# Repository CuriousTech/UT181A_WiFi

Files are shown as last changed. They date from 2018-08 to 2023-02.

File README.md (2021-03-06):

# UT181A_WiFi
Uni-T UT181A WiFi Interface  

Optically isolated interface for the UT181A using the ESP8266 for WiFi in either STA or AP mode. USB Rechargeable 1 cell LiPo and optional OLED display, which should be disabled for speed.  

The code is complete. There should be more export formats though. There's a basic web interface and binary WebSocket for a Windows software interface.  
[WindowsApp](https://www.curioustech.net/ut181a.html)  

  

Web page.  Click the white time on top to update the internal clock. The rest should be the same as what's on the DMM. 
Web  

File manager.  Click Saves or Records for listings. Click on files to download, and X to delete.  
Web

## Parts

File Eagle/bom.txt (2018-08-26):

PCB          OSHPark $7.80 for 3
ESP-07       eBay
USB Micro-B  ZX62D-B-5PA8(30) or common eBay
3V3R         MCP1755T-3302E/OT or MCP1802T-3302I/OT
CC           MCP73831T-2DCI/OT
MICROSWITCH  SSSS810701
BAT (conn)   micro jst 1.25 2 pin
P1           SFH 310
D1           IR LED (T-1)
Q1           SOT23 NPN general purpose
CHG          0805 LED (red)
PROG         4mm button (eBay)

R1           0603 10K=100mA, 2K2=454mA (charge rate)
R2-R4        0805 10K
R5           0805 47
R6           0603 470

C1,C2        0603 0.1uF 10V
C3,C4        0603 4.7uF 10V

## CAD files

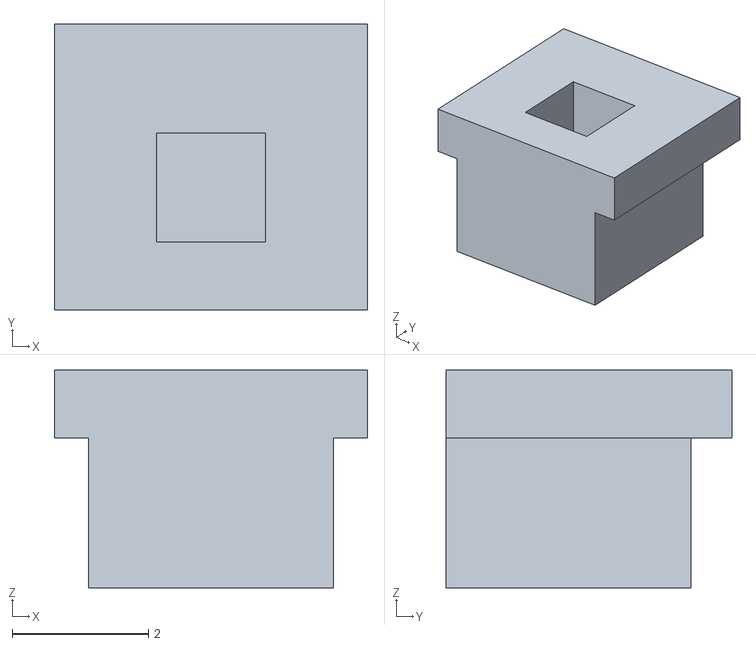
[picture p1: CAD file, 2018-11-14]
3D/switchcover.stl
4.60 x 4.20 x 3.20

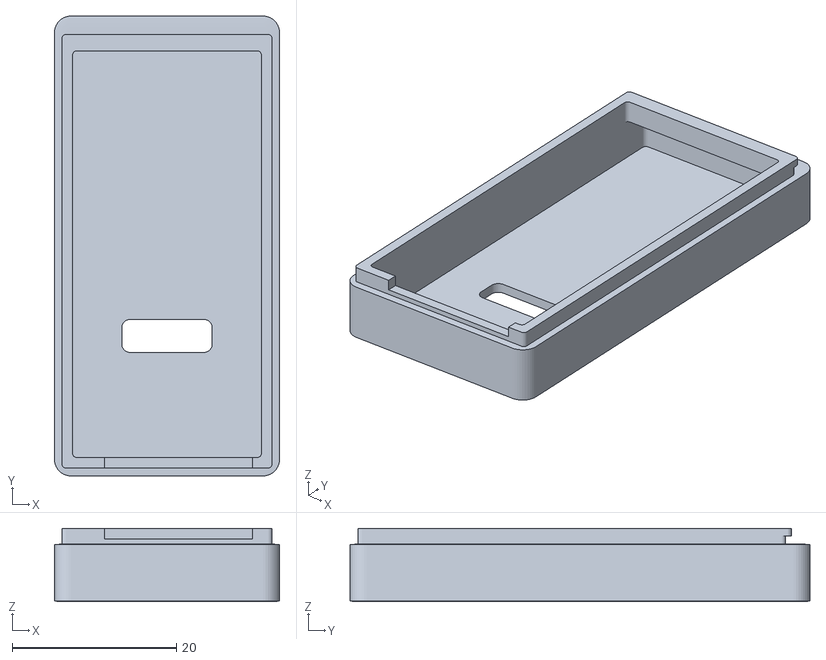
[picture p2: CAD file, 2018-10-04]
3D/UT181ACap.stl
27.4 x 56.0 x 8.90

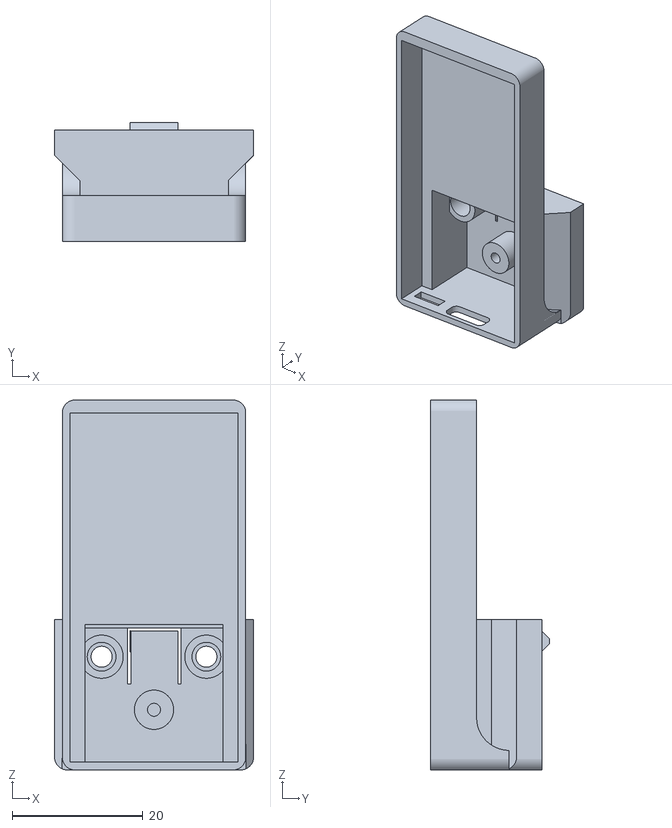
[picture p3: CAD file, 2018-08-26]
3D/UT181ACase.stl
30.4 x 18.1 x 56.5

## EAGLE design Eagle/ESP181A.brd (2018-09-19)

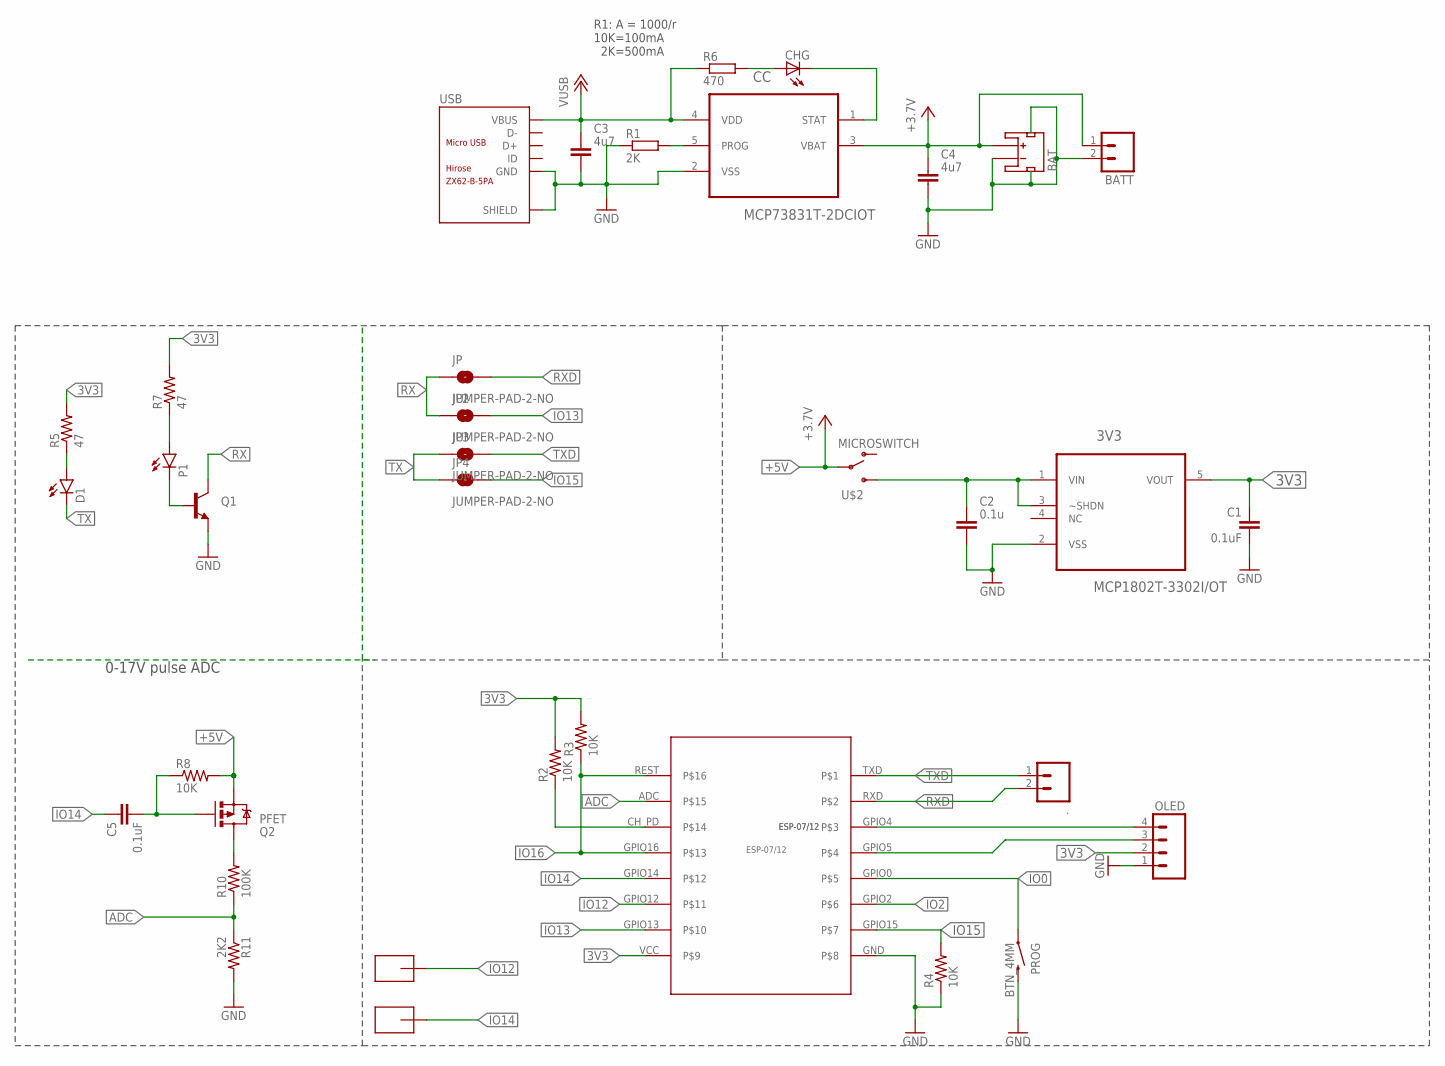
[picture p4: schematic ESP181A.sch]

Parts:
3V3: MCP1802T-3302I/OT; SOT95P270X145-5N
.: M02PTH; 1X02
BAT: JST1.25MM; JST_1.25MM
BATT: M02PTH; 1X02
C1, C5: 0.1uF; 0805-CAP
C2: 0.1u; C603
C3, C4: 4u7; C603
CC: MCP73831T-2DCIOT; SOT95P280X145-5N
CHG: LEDCHIP-LED0805; CHIP-LED0805
D1: LED3MM
JP, JP2, JP3, JP4: JUMPER-PAD-2-NO; PAD-JUMPER-2-NO_NO_SILK
OLED: M04PTH; 1X04
P1: LED3MM
PROG: BTN_4MM
Q1: TRANSISTOR_NPNSOT23-3; SOT23-3
Q2: PFET; SOT23-3
R1: 2K; R603
R2, R3, R4, R8: 10K; 0805
R5, R7: 47; 0805
R6: 470; R603
R10: 100K; 0805
R11: 2K2; 0805
U$1: ESP-07/12
U$2: MICROSWITCH
U$3, U$4: SMD-PAD182X64; SMD-PAD1
USB: ZX62-B-5PA; MICRO-USB5+6P-SMD-0.65-AB

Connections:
3V3: 3V3.5 (VOUT), C1.1, OLED.2, R2.2, R3.2, R5.2, R7.2, U$1.VCC
+5V: BAT.2 (+), BATT.1, C4.1, CC.3 (VBAT), Q2.2 (S), R8.2, U$2.2
ADC: R10.1, R11.1, U$1.ADC
CH_PD: R2.1, U$1.CH_PD
GND: 3V3.2 (VSS), BAT.1 (-), BAT.NC1 (PAD1), BAT.NC2 (PAD2), BATT.2, C1.2, C2.2, C3.2, C4.2, CC.2 (VSS), OLED.1, PROG.2, Q1.2 (E), R1.1, R4.1, R11.2, U$1.GND, USB.5 (GND), USB.P1 (SHIELD), USB.P2 (SHIELD), USB.P3 (SHIELD), USB.P4 (SHIELD), USB.P5 (SHIELD), USB.P6 (SHIELD)
IO0: PROG.1, U$1.GPIO0
IO2: U$1.GPIO2
IO12: U$1.GPIO12, U$4.>PAD
IO13: JP2.2, U$1.GPIO13
IO14: C5.1, U$1.GPIO14, U$3.>PAD
IO15: JP4.2, R4.2, U$1.GPIO15
IO16: R3.1, U$1.GPIO16, U$1.REST
unnamed: D1.A, R5.1
unnamed: P1.K (C), Q1.1 (B)
unnamed: OLED.4, U$1.GPIO4
unnamed: CHG.A, R6.2
unnamed: CC.1 (STAT), CHG.C
unnamed: OLED.3, U$1.GPIO5
unnamed: CC.5 (PROG), R1.2
unnamed: 3V3.1 (VIN), 3V3.3 (~SHDN), C2.1, U$2.3 (S)
unnamed: P1.A, R7.1
unnamed: C5.2, Q2.1 (G), R8.1
unnamed: Q2.3 (D), R10.2
RX: JP.1, JP2.1, Q1.3 (C)
RXD: ..2, JP.2, U$1.RXD
TX: D1.K (C), JP3.1, JP4.1
TXD: ..1, JP3.2, U$1.TXD
VBUS: C3.1, CC.4 (VDD), R6.1, USB.1 (VBUS)

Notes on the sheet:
R1: A = 1000/r 10K=100mA 2K=500mA
0-17V pulse ADC

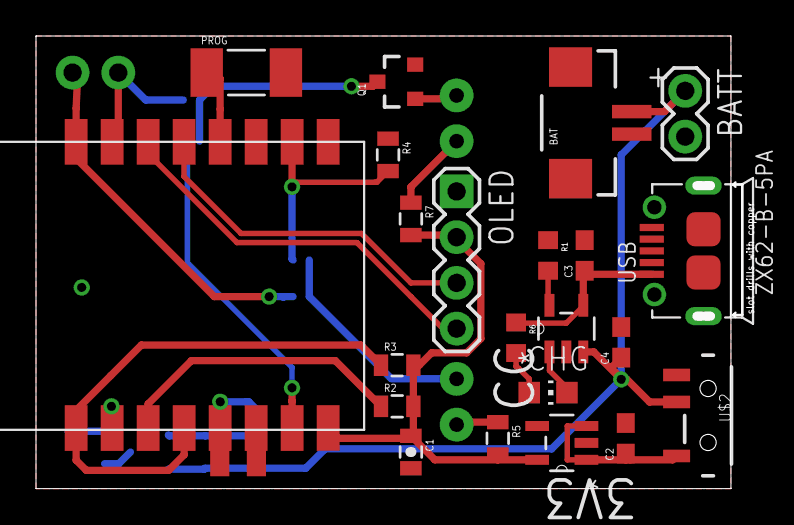
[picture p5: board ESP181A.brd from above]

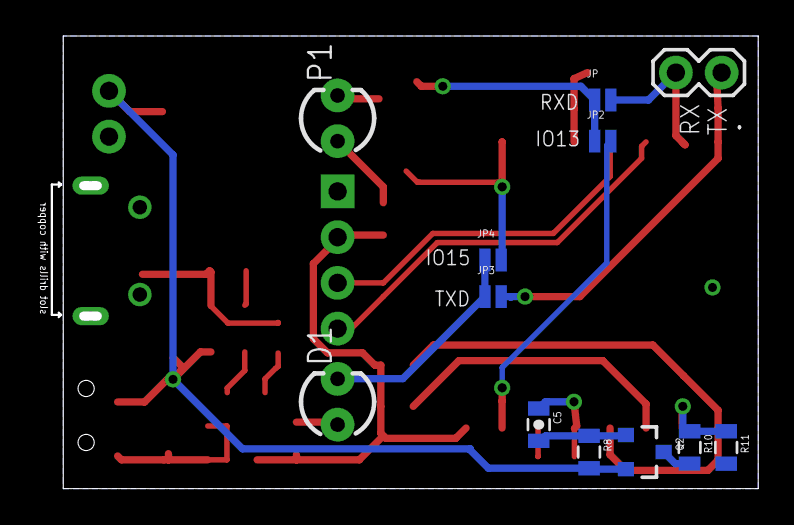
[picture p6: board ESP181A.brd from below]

Board: 2 copper layers, 39.2 x 25.1 mm, 36 parts (12 on the bottom side), 27 nets.

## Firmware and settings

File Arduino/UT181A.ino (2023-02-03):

/**The MIT License (MIT)

Copyright (c) 2018 by Greg Cunningham, CuriousTech

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
THE SOFTWARE IS PROVIDED "AS IS", WITHOUT WARRANTY OF ANY KIND, EXPRESS OR
IMPLIED, INCLUDING BUT NOT LIMITED TO THE WARRANTIES OF MERCHANTABILITY,
FITNESS FOR A PARTICULAR PURPOSE AND NONINFRINGEMENT. IN NO EVENT SHALL THE
AUTHORS OR COPYRIGHT HOLDERS BE LIABLE FOR ANY CLAIM, DAMAGES OR OTHER
LIABILITY, WHETHER IN AN ACTION OF CONTRACT, TORT OR OTHERWISE, ARISING FROM,
OUT OF OR IN CONNECTION WITH THE SOFTWARE OR THE USE OR OTHER DEALINGS IN THE
SOFTWARE.
*/

// Build with Arduino IDE 1.8.12, esp8266 SDK 2.7.1

//uncomment to enable Arduino IDE Over The Air update code
#define OTA_ENABLE

//#define USE_SPIFFS

#include <ssd1306_i2c.h> // https://github.com/CuriousTech/WiFi_Doorbell/tree/master/Libraries/ssd1306_i2c

#include <EEPROM.h>
#include "WiFiManager.h"
#include <ESPAsyncWebServer.h> // https://github.com/me-no-dev/ESPAsyncWebServer
#include <ESP8266mDNS.h>
#include <DNSServer.h>
#include <TimeLib.h> // http://www.pjrc.com/teensy/td_libs_Time.html
#include <UdpTime.h> // https://github.com/CuriousTech/
#include "eeMem.h"
#include <JsonParse.h> // https://github.com/CuriousTech/ESP8266-HVAC/tree/master/Libraries/JsonParse
#include "ut181if.h"
#include "jsonstring.h"
#ifdef OTA_ENABLE
#include <FS.h>
#include <ArduinoOTA.h>
#endif
#ifdef USE_SPIFFS
#include <FS.h>
#include <SPIFFSEditor.h>
#else
#include "pages.h"
#endif

int serverPort = 80;

#define BUTTON     0 // the prog button
#define ESP_LED    2 // low turns on ESP blue LED
#define SCL        4
#define SDA        5
#define SER2_RX   13  //
#define V_PULSE   14
#define SER2_TX   15

SSD1306 display(0x3c, 5, 4); // Initialize the oled display for address 0x3c, sda=5, sdc=4

WiFiManager wifi;  // AP page:  192.168.4.1
AsyncWebServer server( serverPort );
AsyncWebSocket ws("/ws"); // access at ws://[esp ip]/ws
AsyncWebSocket wsb("/bin"); // access at ws://[esp ip]/bin

uint32_t binClientID; // connected binary client
void jsonCallback(int16_t iName, int iValue, char *psValue);
JsonParse jsonParse(jsonCallback);
UdpTime utime;
eeMem ee;

UT181Interface ut;
uint32_t oldOpt;
uint16_t skipCnt;
uint8_t tick;
uint16_t volts;
uint32_t voltTm;

String timeFmt(uint32_t val) // convert seconds to hh:mm:ss
{
  int s = val % 60;
  int m = val / 60 % 60;
  static String st;

  st = String(val/3600);
  st += ":";
  if(m < 10) st += "0";
  st += m;
  st += ":";
  if(s < 10) st += "0";
  st += s;
  return st;
}

String dataJson() // main meter data 10Hz
{
  uint32_t nw = now();
  static uint16_t lastV;

  jsonString js("state");
  js.Var("t", nw - ( (ee.tz + utime.getDST() ) * 3600));
  js.Var("tk", tick);
  js.Var("v", ut.ValueText(0) ); // primary value
  if(ut.m_MData.ShowBar == 0 || ut.m_MData.MinMax) // invalid bar graph (use main value)
  {
    js.Var("bv", ut.ValueText(0));
  }
  else  // 10Hz bar value
  {
    js.Var("bv", (ut.m_MData.type == 6) ? ut.m_MData.u.Ext.Value3.fValue : ut.m_MData.u.Std.fBarValue);
  }

  js.Var("u", ut.UnitText() ); // unit of measurement
  if(ut.m_MData.Recording) // recording timer
  {
    js.Var("v1", timeFmt(ut.m_MData.u.RecTimer.dwElapsed) );
    js.Var("v2", timeFmt(ut.m_MData.u.RecTimer.dwRemain) );
    js.Var("v3", ut.m_MData.u.RecTimer.dwSamples );
  }
  else // normal and others
  {
    if(ut.m_MData.Comp) // comp mode
    {
      const char *p = "PASS";
      if(ut.m_MData.Switch == 4 && ut.m_MData.Select >1) // temp
      {
        if(ut.m_MData.u.CompTemp.Fail) p = "FAIL";
      }
      else if (ut.m_MData.u.Std.Fail) p = "FAIL";
      js.Var("v1", p);
    }
    else
      if(ut.DisplayCnt()>1) js.Var("v1", ut.ValueText(1) );
    if(ut.DisplayCnt() > 2) js.Var("v2", ut.ValueText(2) );
    if(ut.DisplayCnt() > 3) js.Var("v3", ut.ValueText(3) );
  }

  int nMin, nMax, nMod;
  ut.RangeMod(nMin, nMax, nMod);  // min/max/modulo for bar display
  String s = String(nMin) + ",";
  s += nMax; s += ","; s += nMod; 
  js.Var("mm", s);

  bool bAdd = (ut.m_MData.Value.L || ut.m_MData.Value.Blank || ut.m_MData.LeadErr || ut.m_MData.Hold) ? false:true; // skip blanks
  if(ut.Connected() == false) bAdd = false;
  static uint16_t skipList[] = {0,1,4,9,19,49,99,299,599}; // chart logging frequency
  if(ee.rate)
  {
    if(skipCnt++ >= skipList[ee.rate])
      skipCnt = 0;
    else bAdd = false;
  }
  uint16_t st = ut.StatusBits();
  if(bAdd) st |= 1; // add to chart
  js.Var("st", String(st, HEX) ); // bit flags in HEX

  if(ut.m_MData.MinMax) // min max trigger times
  {
    js.Var("t1", ut.m_MData.u.MM.dwTime1);
    js.Var("t2", ut.m_MData.u.MM.dwTime2);
    js.Var("t3", ut.m_MData.u.MM.dwTime3);
  }
  else if(ut.m_MData.Recording)
  {
    js.Var("t1", ut.m_MData.u.RecTimer.dwElapsed);
    js.Var("t2", ut.m_MData.u.RecTimer.dwRemain);
    js.Var("t3", ut.m_MData.u.RecTimer.dwSamples);
  }

  if(nw - voltTm >= 10 || volts != lastV) // every 10 seconds
  {
    voltTm = nw;
    lastV = volts;
    js.Var("vlt", (float)volts / 1000);
  }

  return js.Close();
}

void fixDeg(char *p) // deg kills websocket (try \xB0)
{
  if(*p == 0xB0) *p = '@'; // convert degree to ampersand
  if(p[1] == 0xB0) p[1] = '@';
}

String rangesJson() // get range and select options for dropdowns
{
  const char *rangeList[10][3][10] = {
    {{"Auto", "6", "60", "600", "1000", NULL}, {"Auto", NULL}, {"Auto", NULL}},
    {{"Auto", "600", "60", NULL}, {"Auto", NULL}, {"Auto",NULL}},
    {{"Auto", "6", "60", "600", "1000", NULL}, {"Auto",NULL}, {"Auto",NULL}},
    {{"Auto", "60", "600", NULL}, {"Auto",NULL}, {"Auto",NULL}},
    {{"Auto", "600", "6k", "60k", "600k", "6M", "60M", NULL}, {"Auto",NULL}, {"Auto",NULL} },
    {{"Auto",NULL}, {"Auto", "6n", "60n", "600n", "6µ", "60µ", "600µ", "6m", "60m", NULL},{"Auto",NULL}},
    {{"Auto", "60", "600", "6k", "60k", "600k", "6M", "60M", NULL},
     {"Auto", "60", "600", "6k", "60k", NULL}, {"Auto",NULL} },
    {{"Auto", "600", "6000", NULL}, {"Auto", "600", "6000", NULL}, {"Auto",NULL} },
    {{"Auto", "60", "600", NULL}, {"Auto", "60", "600", NULL}, {"Auto",NULL} },
    {{"Auto",NULL}, {"Auto",NULL}, {"Auto",NULL} },
  };

  const char *optList[10][3][10] = {
    {{"VAC", "VAC,Hz", "Peak", "LowPass", "dBV", "dBM", NULL}, {NULL}, {NULL}},
    {{"mVAC", "mVAC,Hz", "Peak", "AC+DC", NULL}, {NULL}, {NULL}},
    {{"VDC", "AC+DC", "Peak", NULL}, {NULL}, {NULL} },
    {{"mVDC", "Peak", NULL}, {"T1,T2", "T2,T1", "T1-T2", "T2-T1", NULL}, {"T1,T2", "T2,T1", "T1-T2", "T2-T1", NULL}},
    {{"Ohms",NULL}, {"Short", "Open", NULL}, {"nS", NULL}},
    {{"Normal", "Alarm", NULL}, {"Cap", NULL}, {NULL}},
    {{"Hz", NULL}, {"%", NULL}, {"Pulse", NULL}},
    {{"µADC", "AC+DC", "Peak", NULL}, {"µAAC", "µAAC,Hz", "Peak", NULL}, {NULL}},
    {{"mADC", "AC+DC", "Peak", NULL}, {"mAAC", "mAAC,Hz", "Peak", NULL}, {NULL}},
    {{"ADC", "AC+DC", "Peak", NULL}, {"AAC", "AAC,Hz", "Peak", NULL}, {NULL}},
  };

  const char *selList[10][4] = {
    {"VAC", NULL},
    {"mVAC", NULL},
    {"VDC", NULL },
    {"mVDC", "C", "F",NULL},
    {"Ohms", "Cont", "nS", NULL},
    {"Diode", "Cap", NULL},
    {"Hz", "%", "Pulse",NULL},
    {"µADC", "µAAC", NULL},
    {"mADC", "mAAC", NULL},
    {"ADC", "AAC", NULL},
  };

  uint8_t sw = ut.m_MData.Switch - 1;
  if(sw >= 10) sw = 0;
  uint8_t sel = ut.m_MData.Select - 1;
  if(sel >= 3) sel = 0;

  int i;

  jsonString js("range");

  js.Var("rs", ut.m_MData.Range);
  js.Var("os", ut.m_MData.Select);
  js.Array("s", selList[sw] );
  js.Array("r", rangeList[sw][sel] );
  js.Array("o", optList[sw][sel] );

  const char *szUnits[4];
  szUnits[0] = NULL;
  szUnits[1] = NULL;
  szUnits[2] = NULL;
  szUnits[3] = NULL;
  if(ut.m_MData.MinMax) // extended units of measurement
  {
    fixDeg(ut.m_MData.u.MM.szUnit);
    szUnits[0] = ut.m_MData.u.MM.szUnit;
    szUnits[1] = ut.m_MData.u.MM.szUnit;
    szUnits[2] = ut.m_MData.u.MM.szUnit;
  }
  else if(ut.m_MData.Peak)
  {
    fixDeg(ut.m_MData.u.Ext.szUnit1);
    szUnits[0] = ut.m_MData.u.Ext.szUnit1;
  }
  else if(ut.m_MData.Switch==4 && ut.m_MData.Select > 1) // temp C or F
  {
    fixDeg(ut.m_MData.u.Std.szUnit);
    szUnits[0] = ut.m_MData.u.Std.szUnit;
    if(ut.m_MData.Mode >= 3)
     szUnits[1] = ut.m_MData.u.Std.szUnit;
  }
  else if(ut.m_MData.type == 3 || ut.m_MData.type == 6)
  {
    fixDeg(ut.m_MData.u.Ext.szUnit1);
    fixDeg(ut.m_MData.u.Ext.szUnit2);
    szUnits[0] = ut.m_MData.u.Ext.szUnit1;
    szUnits[1] = ut.m_MData.u.Ext.szUnit2;
  }
  else if(ut.m_MData.type == 7)
  {
    fixDeg(ut.m_MData.u.Ext.szUnit1);
    fixDeg(ut.m_MData.u.Ext.szUnit2);
    fixDeg(ut.m_MData.u.Ext.szUnit3);
    szUnits[0] = ut.m_MData.u.Ext.szUnit1;
    szUnits[1] = ut.m_MData.u.Ext.szUnit2;
    szUnits[2] = ut.m_MData.u.Ext.szUnit3;
  }

  js.Array("u", szUnits );

  String sLabels[5];

  if(ut.m_MData.MinMax) // labels
  {
      sLabels[0] = "MAX MIN";
      sLabels[1] = "Maximum";
      sLabels[2] = "Average";
      sLabels[3] = "Minimum";
  }
  else if(ut.m_MData.Recording)
  {
      sLabels[0] = "REC";
      sLabels[1] = "Elapsed Time:";
      sLabels[2] = "Remain Time:";
      sLabels[3] = "Samples:";
  }
  else if(ut.m_MData.Rel)
  {
      sLabels[0] = "REL"; 
      sLabels[1] = "Reference:";
      sLabels[2] = "Measurement:";
  }
  else if(ut.m_MData.Switch==4 && ut.m_MData.Select > 1) // Temp C or F
  {
      sLabels[0] = "";
      if(ut.m_MData.Mode >= 3) // subtractive
      {
        sLabels[1] = "T1";
        sLabels[2] = "T2";
      }
      else if(ut.m_MData.Mode == 2) // reverse
      {
        sLabels[1] = "T1";
      }
      else // normal
      {
        sLabels[1] = "T2";
      }
  }
  else if(ut.m_MData.Comp)
  {
      const char *compM[] = {"INNER", "OUTER", "< VALUE", "> VALUE"};
      sLabels[0] = "";

      if(ut.m_MData.Switch == 4 && ut.m_MData.Select >1) // temp
      {
        sLabels[1] = "MODE: "; sLabels[1] += compM[ut.m_MData.u.CompTemp.CompMode];
        sLabels[2] = "LOW:  "; sLabels[2] += ut.m_MData.u.CompTemp.fLow;
        sLabels[3] = "HIGH: "; sLabels[3] += ut.m_MData.u.CompTemp.fHigh;
      }
      else
      {
        sLabels[1] = "MODE: "; sLabels[1 ]+= compM[ut.m_MData.u.Std.CompMode];
        switch(ut.m_MData.u.Std.CompMode)
        {
          case 0:
          case 1:
            sLabels[2] = "LOW:  "; sLabels[2] += ut.m_MData.u.Std.fLow;
            sLabels[3] = "HIGH: "; sLabels[3] += ut.m_MData.u.Std.fHigh;
            break;
          case 2:
          case 3:
            sLabels[2] = "VALUE:  "; sLabels[2] += ut.m_MData.u.Std.fHigh;
            break;
        }
      }
  }

  js.Array("l", sLabels );

  return js.Close();
}

String settingsJson() // EEPROM settings
{
  jsonString js("settings");
  js.Var("tz", ee.tz);
  js.Var("o", ee.bEnableOLED);
  js.Var("f", ee.exportFormat);
  js.Var("r", ee.rate);
  return js.Close();
}

void parseParams(AsyncWebServerRequest *request) // parse URL params
{
  char password[64];
 
  if(request->params() == 0)
    return;

  for ( uint8_t i = 0; i < request->params(); i++ ) {
    AsyncWebParameter* p = request->getParam(i);
    String s = request->urlDecode(p->value());
    bool which = (tolower(p->name().charAt(1) ) == 'd') ? 1:0;
    int val = s.toInt();
 
    switch( p->name().charAt(0)  )
    {
      case 'O': // OLED
          ee.bEnableOLED = (s == "true") ? true:false;
          display.clear();
          display.display();
          break;
      case 's': // ssid
          s.toCharArray(ee.szSSID, sizeof(ee.szSSID));
          break;
      case 'p': // pass
          wifi.setPass(s.c_str());
          break;
    }
  }
}

const char *jsonList1[] = { // WebSocket commands
  "oled", // 0
  "TZ",
  "hold",
  "mm", // minmax
  "range",
  "sel",
  "opt",
  "rel",
  "rec",
  "svs",
  "name", // 10
  "int",
  "sav",
  "stop",
  "file",
  "snap", //15
  "fmt",
  "delf",
  "dels",
  "rate",
  "sclk", // 20
  NULL
};

void jsonCallback(int16_t iName, int iValue, char *psValue) // handle WebSocket commands
{
  uint8_t sel;
  static char szName[16];
  static uint32_t wInterval;

  switch(iName)
  {
    case 0: // OLED
      ee.bEnableOLED = iValue ? true:false;
      break;
    case 1: // TZ
      ee.tz = iValue;
      break;
    case 2: // hold
      ut.Hold();
      break;
    case 3: // mm
      ut.MinMax();
      break;
    case 4: // range
      ut.SetRange(iValue);
      break;
    case 5: // select
      ut.SetSelect(iValue, 0, false, 0);
      break;
    case 6: // opt
      ut.SetSelect(ut.m_MData.Select, iValue, false, 0);
      break;
    case 7: // rel
      sel = ut.m_MData.Select;
      if(ut.m_MData.Rel)
        ut.SetSelect(sel, 0, false, 0);
      else
        ut.SetSelect(sel, 0, true, ut.GetfValue());
      break;
    case 8: // records
      ut.getRecordCount();
      break;
    case 9: // saves
      ut.getSaveCount();
      break;
    case 10: // name
      strncpy(szName, psValue, sizeof(szName)-1);
      break;
    case 11: // interval
      if(strlen(psValue)==0)
        iValue = 1;
      wInterval = iValue;
      break;
    case 12: //save (duration)
      if(iValue == 0)
        ut.Save();
      else
      {
        if(strlen(szName) == 0) strcpy(szName, "Record_01");
        if(wInterval == 0) wInterval = 1;
        ut.StartRecord(szName, wInterval, iValue);
        jsonString js("print");
        String s = "Start record ";
        s += szName;
        s += " ";
        s += wInterval;
        s += " ";
        s += iValue;
        js.Var("data", s);
        WsSend(js.Close());
      }
      break;
    case 13: // stop
      if(ut.m_MData.Recording)
        ut.StopRecord();
      break;
    case 14: // file
      ut.startRecordRetreval(iValue, szName, wInterval);
      break;
    case 15: // snap
//        ut.getSave(iValue, true);
      break;
    case 16: // fmt
      ee.exportFormat = iValue;
      break;
    case 17: // delf
      ut.deleteRecord(iValue + 1);
      break;
    case 18: //dels
      ut.deleteSave(iValue + 1);
      break;
    case 19: // rate
      ee.rate = iValue;
      skipCnt = 0;
      break;
    case 20: // sclk
      ut.setClock();
      break;
  }
}

void sendSaveEntry(SaveRec *pRec)
{
  String s = "[[\"";

  s += ut.convertDate(pRec->Date);
  s += "\"],[\"";
  s += ut.ValueText(pRec->Value0);
  s += "\"],[\"";

  if(pRec->type == 3) // MaxMin
  {
      fixDeg(pRec->u.b.szLabel);
      s += pRec->u.b.szLabel;
      s += "\"],[\""; s += ut.ValueText(pRec->u.b.Value21);
      s += "\"],[\""; s += ut.ValueText(pRec->u.b.Value22);
      s += "\"],[\""; s += ut.ValueText(pRec->u.b.Value23);
      s += "\"]]";
  }
  else if( pRec->type == 0) // normal
  {
      fixDeg(pRec->u.a.szLabel0);
      s += pRec->u.a.szLabel0;
      s += "\"]]";    
  }
  else if(pRec->type == 6) // 3 values
  {
      fixDeg(pRec->u.a.szLabel0);
      fixDeg(pRec->u.a.szLabel1);
      fixDeg(pRec->u.a.szLabel2);
      s += pRec->u.a.szLabel0;
      s += "\"],[\""; s += ut.ValueText(pRec->u.a.Value11);
      s += "\"],[\""; s += pRec->u.a.szLabel1;
      s += "\"],[\""; s += ut.ValueText(pRec->u.a.Value12);
      s += "\"],[\""; s += pRec->u.a.szLabel2;
      s += "\"]]";    
  }
  else if(pRec->type == 7) // 4 values
  {
      fixDeg(pRec->u.b.szLabel);
      s += pRec->u.b.szLabel;
      s += "\"],[\""; s += ut.ValueText(pRec->u.b.Value21);
      s += "\"],[\""; s += pRec->u.b.szLabel;
      s += "\"],[\""; s += ut.ValueText(pRec->u.b.Value22);
      s += "\"],[\""; s += pRec->u.b.szLabel;
      s += "\"],[\""; s += ut.ValueText(pRec->u.b.Value23);
      s += "\"],[\""; s += pRec->u.b.szLabel;
      s += "\"]]";    
  }
  else // 2 values
  {
      fixDeg(pRec->u.a.szLabel1);
      fixDeg(pRec->u.a.szLabel2);
      s += pRec->u.a.szLabel1;
      s += "\"],[\""; s += ut.ValueText(pRec->u.a.Value11);
      s += "\"],[\""; s += pRec->u.a.szLabel2;
      s += "\"]]";
  }
  jsonString js("save");
  js.VarNoQ("data", s);
  js.Var("b", pRec->type);
  ws.textAll(js.Close());
}

void sendRecordEntry(Record *pRecord)
{
  String s = "[[\"";
  s += pRecord->szName;
  s += "\"],[\""; s += ut.convertDate(pRecord->Date);
  fixDeg(pRecord->szUnit);
  s += "\"],[\""; s += pRecord->szUnit;
  s += "\"],[\""; s += pRecord->dwSamples;
  s += "\"],[\""; s += pRecord->wInterval;
  s += "\"],[\""; s += pRecord->dwDuration;
  s += "\"],[\""; s += ut.ValueText(pRecord->mMin);
  s += "\"],[\""; s += ut.ValueText(pRecord->mAvg);
  s += "\"],[\""; s += ut.ValueText(pRecord->mMax);
  s += "\"]]";

  jsonString js("record");
  js.VarNoQ("data", s);
  ws.textAll(js.Close());
}

void WsSend(String s) // send packat directly (preformatted)
{
  ws.textAll(s);  
}

void onWsEvent(AsyncWebSocket * server, AsyncWebSocketClient * client, AwsEventType type, void * arg, uint8_t *data, size_t len)
{  //Handle WebSocket event

  switch(type)
  {
    case WS_EVT_CONNECT:      //client connected
      client->keepAlivePeriod(50);
      client->text(dataJson());
      client->text(settingsJson());
      client->ping();
      oldOpt = 0;
      break;
    case WS_EVT_DISCONNECT:    //client disconnected
      break;
    case WS_EVT_ERROR:    //error was received from the other end
      break;
    case WS_EVT_PONG:    //pong message was received (in response to a ping request maybe)
      break;
    case WS_EVT_DATA:  //data packet
      AwsFrameInfo * info = (AwsFrameInfo*)arg;
      if(info->final && info->index == 0 && info->len == len){
        //the whole message is in a single frame and we got all of it's data
        if(info->opcode == WS_TEXT){
          data[len] = 0;
          jsonParse.process((char*)data);
        }
      }
      break;
  }
}

void onBinEvent(AsyncWebSocket * server, AsyncWebSocketClient * client, AwsEventType type, void * arg, uint8_t *data, size_t len)
{  //Handle binary WebSocket event (/bin)
  String s;
  uint8_t buf[] = {1,8,1,0xA}; // identifier response

  switch(type)
  {
    case WS_EVT_CONNECT:      //client connected
      client->keepAlivePeriod(50);
      binClientID = client->id();
      client->binary(buf, sizeof(buf));
      client->ping();
      break;
    case WS_EVT_DISCONNECT:    //client disconnected
      binClientID = 0;
      break;
    case WS_EVT_ERROR:    //error was received from the other end
      break;
    case WS_EVT_PONG:    //pong message was received (in response to a ping request maybe)
      break;
    case WS_EVT_DATA:  //data packet
      AwsFrameInfo * info = (AwsFrameInfo*)arg;
      if(info->final && info->index == 0 && info->len == len){
        //the whole message is in a single frame and we got all of it's data
          ut.WriteData(data, len); // Raw command. No ABCD, length, or checksum
      }
      break;
  }
}

volatile bool bButtonPressed;

void btnISR() // Prog button on board
{
  bButtonPressed = true;
}

const char hostName[] ="UT181A";

inline void ICACHE_RAM_ATTR buttonISR()
{
  
}

void setup()
{
  pinMode(ESP_LED, OUTPUT);
  pinMode(V_PULSE, OUTPUT);
  digitalWrite(ESP_LED, LOW);

  attachInterrupt(BUTTON, buttonISR, FALLING);
  
  // initialize dispaly
  display.init();
//  display.flipScreenVertically();
  display.clear();
  display.display();

  Serial.begin(9600);

  WiFi.hostname(hostName);
  wifi.autoConnect(hostName, "password");

#ifdef USE_SPIFFS
  SPIFFS.begin();
  server.addHandler(new SPIFFSEditor("admin", "admin"));
#endif

  // attach AsyncWebSocket
  ws.onEvent(onWsEvent);
  server.addHandler(&ws);
  wsb.onEvent(onBinEvent);
  server.addHandler(&wsb);

  server.on( "/", HTTP_GET | HTTP_POST, [](AsyncWebServerRequest *request){
      parseParams(request);
#ifdef USE_SPIFFS
      request->send(SPIFFS, "/index.html");
#else
      request->send_P(200, "text/html", page1);
#endif
  });
  server.on( "/s", HTTP_GET | HTTP_POST, [](AsyncWebServerRequest *request){
    parseParams(request);
    request->send( 200, "text/html", wifi.page() );
  });
  server.on( "/files.html", HTTP_GET | HTTP_POST, [](AsyncWebServerRequest *request){
#ifdef USE_SPIFFS
    request->send( SPIFFS, "/files.html" );
#else
    request->send_P( 200, "text/html", files_html );
#endif
  });
  server.on("/heap", HTTP_GET, [](AsyncWebServerRequest *request){
    request->send(200, "text/plain", String(ESP.getFreeHeap()));
  });
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
void loop()
{
  static uint8_t hour_save, sec_save, lastS;
  static uint8_t cnt;
  time_t nw;

  MDNS.update();
#ifdef OTA_ENABLE
  ArduinoOTA.handle();
#endif
  utime.check(ee.tz);

  wifi.service();
  if(wifi.connectNew())
  {
    if(!MDNS.begin( hostName ) )
      Serial.println("Error setting up mDNS");
    MDNS.addService("iot", "tcp", 8080);
  }
  nw = now();
  int s = second(nw);
  if(s !=lastS)
  {
    lastS = s;
    tick = 0;
  }
  ut.service(nw); // read serial data

  if(ut.Updated() || tick==0) // new packet ready, or not receiving
  {
    ws.textAll(dataJson());
    tick++;
  }
  // only update the extras when settings change
  if(oldOpt != *(uint32_t*)(&ut.m_MData))
  {
    oldOpt = *(uint32_t*)(&ut.m_MData); // switch/sel is here as well
    ws.textAll(rangesJson());
  }

  if(sec_save != s) // only do stuff once per second
  {
    sec_save = s;
    if(s == 0 && hour_save != hour(nw))
    {
      hour_save = hour(nw);
      if(hour_save == 2)
      {
        utime.start(); // update time daily at DST change
      }
      ee.update(); // update EEPROM if needed while we're at it (give user time to make many adjustments)
    }

    static uint8_t connTime = 1;
    if(--connTime == 0)
    {
      connTime = 5;
      if(ut.m_bConnected == false)
        ut.start(true);
    }
    digitalWrite(V_PULSE, LOW);
    uint16_t v = analogRead(0);
    volts = (v * 5.25);
    digitalWrite(V_PULSE, HIGH);
  }

  // draw the screen here
  if(ee.bEnableOLED)
  {
    display.clear();
    display.drawPropString( 2, 23, ut.ValueText(0) );
    display.drawPropString(80, 47, ut.UnitText() );
    display.updateChunk();
  }
}

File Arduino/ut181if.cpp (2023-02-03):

#include "ut181if.h"
#include "eeMem.h"
#include <TimeLib.h>
#include "jsonstring.h"

extern void sendBinData(uint8_t *p, int len);
extern void sendSaveEntry(SaveRec *pRec);
extern void sendRecordEntry(Record *pRecord);
extern void WsSend(String s);

void UT181Interface::service(time_t nw)
{
  String s;
  while(Serial.available())
  {
    uint8_t c = Serial.read();
    m_keepAlive = nw;
    switch(m_state)
    {
      case 0:     // data packet: AB CD len len ............. chk chk
        if(c == 0xAB)
          m_state = 1;
        else if(c == 0xCD)
          m_state = 2;
        else
        {
          WsPrint("Expected AB got " + String(c, HEX));
        }
        break;
      case 1:
        if(c == 0xCD)
          m_state = 2;
        else
        {
          m_state = 0; // unexpected value
          WsPrint("Expected CD got " + String(c, HEX) );
        }
        break;
      case 2:
        m_len = (uint16_t)c;
        m_state = 3;
        break;
      case 3:
        m_len |= (uint16_t)(c << 8);
        if(m_len > 3000)
        {
          WsPrint("Unexpected length " + m_len);
          m_len = 1;
        }
        m_state = 4;
        m_idx = 0;
        break;
      case 4:
        m_buffer[m_idx++] = c;
        if(m_idx == m_len || m_idx >= sizeof(m_buffer) )
        {
          if( sum(m_buffer, m_len-2) == (m_buffer[m_len-2] | (m_buffer[m_len-1]<<8)) )
          {
            delay(1);
            process_sentence(m_len-2);
          }
          else
          {
            WsPrint("Checksum error");
            digitalWrite(2, LOW); // strobe LED
            delay(5);
            digitalWrite(2, HIGH);
          }
          m_state = 0;
          m_idx = 0;
          m_len = 0;
        }
        break;
    }
  }
  if((nw - m_keepAlive) > 3) // timeout should cause a restart if stopped
  {
    m_keepAlive = nw;
    m_bConnected = false;
    WsPrint("Serial timeout");
    m_state = 0;
    m_idx = 0;
    m_len = 0;
    m_nRecReq = 0;
    m_nRecordItem = 0;
  }
}

void UT181Interface::WsPrint(String text)
{
  String s = "{\"cmd\":\"print\",\"text\":\"";
  s += text;
  s += "\"}";
  WsSend(s);
}

bool UT181Interface::Updated() // check for new primary data packet update
{
  bool u = false;
  static int n;

  if(n != m_Updated) u = true;
  n = m_Updated;
  return u;
}

bool UT181Interface::Connected()
{
  return m_bConnected;
}

void UT181Interface::process_sentence(uint16_t len)
{
  sendBinData(m_buffer, len);

  switch(m_buffer[0])
  {
    case RX_ACK:  // 1 = command respsonses
          // 01 4F 4B A0 = 'OK '
          // 01 45 52 9D = 'ER'
          // 01 49 4E 56 = 'INV'
      if(m_nRecReq) // serialized start of file list retrieval
      {
        GetRecordSeq();
      }
      if(m_bGetRecStart)  // serialized start of large data retrieval
      {
        m_bGetRecStart = false;
        getRecordData();
      }

      break;
    case RX_MDATA: // main meter data
      m_bConnected = true;
      memcpy(&m_MData, m_buffer + 1, sizeof(MData));
      m_Updated++;
      break;
    case RX_SAVE_ENT: // save entry
      if(m_nRecIdx >= m_nSaves)
      {
        m_nRecReq = 0; // too many
        break;
      }
      sendSaveEntry( (SaveRec*)(m_buffer + 1));

      if(++m_nRecIdx < m_nSaves)
        GetRecordSeq(); // get more
      else // finished
      {
        m_nRecReq = 0;
        start(true);
      }
      break;

    case RX_REC_ENT: // record entry
      if(m_nRecIdx >= m_nRecords)
      {
        m_nRecReq = 0;
        break;
      }

      sendRecordEntry( (Record*)(m_buffer + 1));

      if(++m_nRecIdx < m_nRecords)
      {
        GetRecordSeq();
      }
      else // end, reconnect
      {
        m_nRecReq = 0;
        start(true);
      }
      break;
    case RX_REC_DATA: // record data
      decodeSamples(m_buffer + 2, m_buffer[1]); // first byte is count
      m_nRecDataIndex += m_buffer[1];
      if(m_nRecDataIndex < m_nRecDataIndexEnd)
      {
        getRecordData();
      }
      else // end of record, restart
      {
        m_nRecordItem = 0;
        start(true);
        WsSend("{\"cmd\":\"finish\"");
      }
      break;
    case RX_REC_CNT:  // number of saves/records, model
      switch(m_buffer[1])
      {
        case CMD_GET_SAVE_COUNT: // saves
          m_nSaves = getWord(m_buffer + 2);
          if(m_nSaves == 0)
            break;
          start(false); // disable to read
          m_nRecReq = 1; // setup to start on next ack
          m_nRecIdx = 0;
          break;
        case CMD_GET_RECORD_COUNT: // records
          m_nRecords = getWord(m_buffer + 2);
          if(m_nRecords == 0)
            break;
          start(false); // disable main data to read
          m_nRecReq = 2;
          m_nRecIdx = 0;
          break;
        case CMD_QUERY_MODEL:
          strcpy(m_szModel, (char *)m_buffer + 2);
          strcpy(m_szSerial, (char *)m_buffer + 13);
          break;
        default:
          break;
      }
      break;
  }
}

uint16_t UT181Interface::getWord(uint8_t *p)
{
  uint16_t *wP = (uint16_t*)p;
  return *wP;
}

void UT181Interface::startRecordRetreval(int nItem, char *pszUnit, uint32_t dwSamples)
{
  if(nItem >= m_nRecords)
    return;

  strcpy(m_szRecUnit, pszUnit);
  m_nRecDataIndex = 0;
  m_nRecDataIndexEnd = dwSamples;
  m_bGetRecStart = true;
  start(false);
  m_nRecordItem = nItem + 1;
}

void UT181Interface::start(bool bCont) // start/stop meter data transmit, or single (responds with ACK)
{
  static uint8_t cmd[]= {CMD_CONT_DATA, 0x00};

  if( m_nRecReq || m_nRecordItem) // in download mode
    return;

  if(!bCont)  m_bConnected = false;

  cmd[1] = bCont ? 1 : 0;
  Write(cmd, sizeof(cmd) );
}

uint16_t UT181Interface::sum(uint8_t *p, uint16_t len)
{
  uint16_t ch = 2;

  for(uint16_t i = 0; i < len; i++)
    ch += p[i];
  ch += (len >> 8);
  return ch + (len & 0xFF);
}

 // Write data from binary socket
void UT181Interface::WriteData(uint8_t *pData, int len)
{
  Write(pData, len);
}

// Write data to serial IR LED
bool UT181Interface::Write(uint8_t *p, uint8_t len)
{
  uint8_t buf[64] = {0};

  buf[0] = 0xAB;
  buf[1] = 0xCD;
  buf[2] = len + 2;
  buf[3] = 0;

  uint16_t ck = buf[2];
  int i;
  for(i = 0; i < len; i++)
  {
    buf[i+4] = p[i];
    ck += p[i];
  }
  buf[i+4] = ck & 0xFF;
  buf[i+5] = ck >> 8;

  return Serial.write(buf, len+6);
}

// Select and REL + rel value
void UT181Interface::SetSelect(uint8_t nSel, uint8_t nOpt, bool bRel, float fValue)
{
  uint8_t cmd[]= {CMD_SET_OPTION, ((nOpt + 1) << 4) | (bRel ? 2:1), (m_MData.Switch << 4) | nSel};

  if(cmd[2] == 0x52 || cmd[2] == 0x61) // mode for cont, diode
  {
    cmd[1] = 0x10 | (nOpt + 1);
  }

  Write(cmd, sizeof(cmd) );
  if(bRel)
  {
      #pragma pack(push, 1)
      struct relCmd
      {
        uint8_t Cmd;
        float fVal;
      };
      #pragma pack(pop)

      relCmd rc = {CMD_SET_REL, fValue};

      Write((uint8_t*)&rc, sizeof(rc) );
  }
}

float UT181Interface::GetfValue()
{
  return m_MData.Value.fValue;
}
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

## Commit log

2018-09-19 Added battery voltage monitor
    [ESP181A.brd, ESP181A.sch]
2018-09-25 temperature label fixes
2018-10-04 Fixed 10Hz bar update
2018-10-04 Added OLED hole
    [UT181ACap.stl]
2018-10-15 Batt voltage, centered items
2018-10-15 Batt voltage, reverted bits
    [UT181A.ino]
2018-10-16 fixed some unit labels
    [UT181A.ino]
2019-04-13 fix for 2.5.0 and bug
    [ut181if.cpp]
2026-08-27 Add eagle.epf configuration file for Eagle CAD
2026-08-27 Forgot the ADC, changed TX pin to safer one

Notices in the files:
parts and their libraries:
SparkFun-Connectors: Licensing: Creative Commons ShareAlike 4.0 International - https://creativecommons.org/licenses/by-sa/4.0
